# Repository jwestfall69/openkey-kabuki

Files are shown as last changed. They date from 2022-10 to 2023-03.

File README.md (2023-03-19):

# openkey-kabuki
* [Overview](#overview)
* [Project Status](#project-status)
* [Supported Games](#supported-games)
  * [Mitchell](#mitchell)
  * [CPS 1.5 (QSound CPU)](#cps-15-qsound-cpu)
* [Hardware](#hardware)
  * [PCB Manufacturing](#pcb-manufacturing)
  * [BOM](#bom)
  * [Assembly](#assembly)
* [Programming](#programming)
  * [Hardware](#hardware-1)
  * [Software](#software)
* [Installation](#installation)
  * [Mitchell DBS Identify/Removal](#mitchell-dbs-identifyremoval)
  * [CPS 1.5 (QSound CPU) DBS Identify/Removal](#cps-15-qsound-cpu-dbs-identifyremoval)

## Overview
This is an opensource/hardware implementation of an on the fly kabuki CPU key programmer that consists of a PCB that sits between the CPU socket and the kabuki CPU.  The kabuki CPU is found in Mitchell and CPS 1.5 arcade boards and contains keys for decrypting/decoding the program roms.

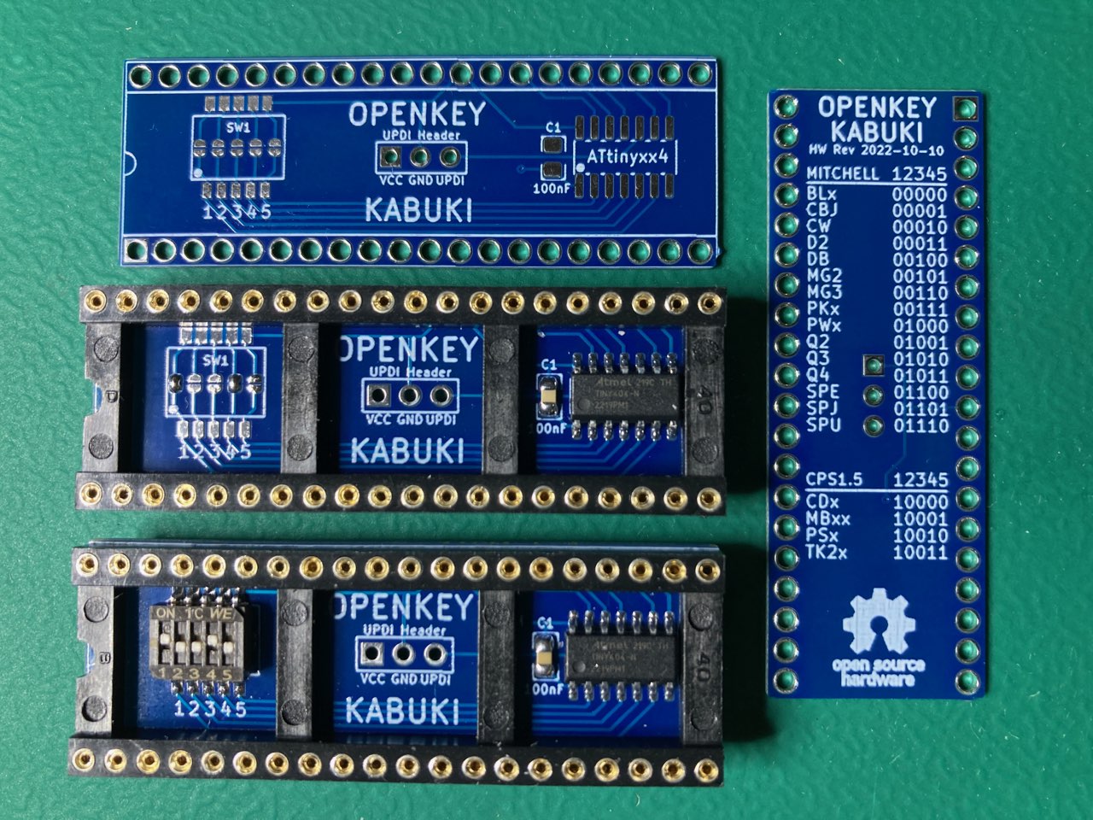
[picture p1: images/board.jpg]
board pics


Installed:<br>
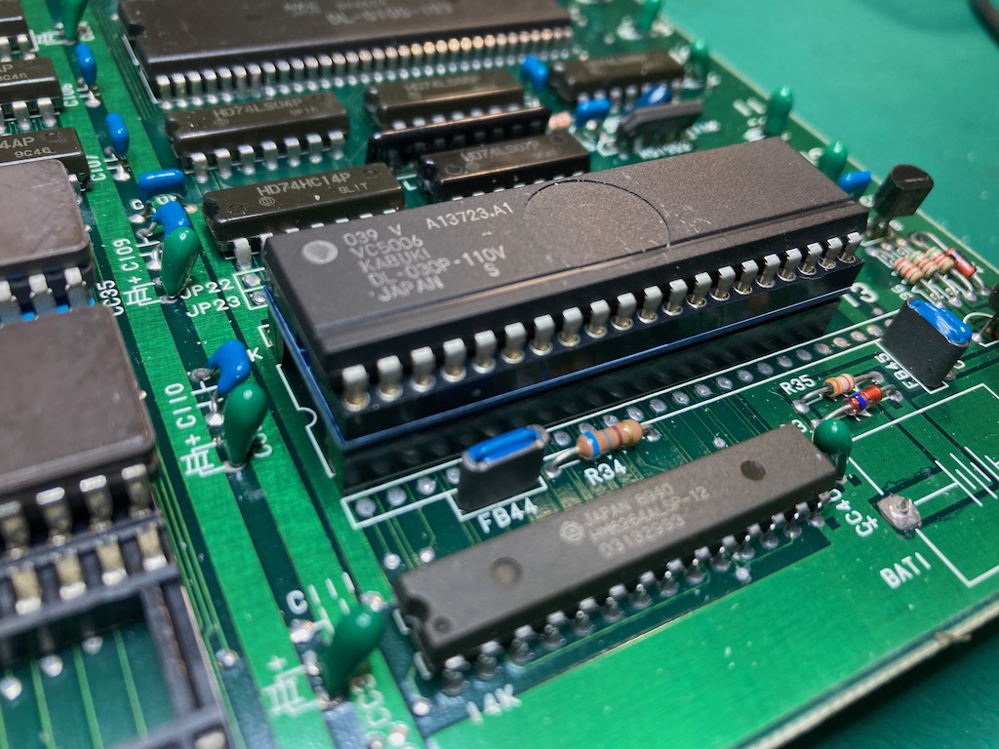
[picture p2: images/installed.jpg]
installed


This project is providing the same functionality as [Undamned's InfiniKey-Kabuki](https://www.arcade-projects.com/threads/infinikey-kabuki.8338/).  The lack of supply is what prompted me to make openkey-kabuki.  If they ever end up coming back in stock please consider purchasing those to support [Undamned](https://www.arcade-projects.com/forums/temple-of-the-undamned.77/)'s work.

Details on *how* to program a kabuki CPU's key data can be found in [Eduardo Cruz](http://arcadehacker.blogspot.com/)'s [write up](http://arcadehacker.blogspot.com/2014/11/capcom-kabuki-cpu-intro.html) and [youtube video](https://www.youtube.com/watch?v=9t-9hQEOjLI).

Details on *what* to program can be found in MAME's decryption code for the [kabuki CPU](https://github.com/mamedev/mame/blob/master/src/mame/capcom/kabuki.cpp#L73).

## Project Status
**PCB:** I would consider the design PCB done at this point.  I'm open to any input on changes/improvements as this is my first PCB design.

**Firmware:** Need to get untested games tested

**Documentation:** Done

## Supported Games
openkey-kabuki supports either having a 5 position switch or using solder jumpers for picking which game key to use.  For the switch, ensure the switches are fully set.  You should hear a click sound as you change the position.

Below is a list of supported games and what switches/jumpers must be used for each.

#### Mitchell
| Switch<br>12345 | Program ROM Labels | MAME Sets | Game Names | Tested / Working |
|---|:---:|---|---|:---:|
| 00000 | BLE<br>BLJ | block<br>blockj | Block Block | YES (conversion)|
| 00001 | CBJ | cbasebal | Capcom Baseball | |
| 00010 | CW | cworld | Capcom World | YES (conversion) |
| 00011 | D2 | dokaben2 | Dokaben 2 | YES (conversion) |
| 00100 | DB | dokaben | Dokaben | YES (conversion) |
| 00101 | MG2 | mgakuen2 | Mahjong Gakuen 2 Gakuen-chou no Fukushuu | YES |
| 00110 | MG3 | marukin | Super Marukin-Ban | YES (conversion) |
| 00111 | PK<br>PKO | pkladiesl<br>pkladies | Poker Ladies | YES (conversion) |
| 01000 | PWE<br>PWJ<br>PWU | pang<br>pompingw<br>bbros | Pang<br>Pomping World<br>Buster Bros | YES |
| 01001 | Q2 | hatena | Adventure Quiz 2 - Hatena? no Daibouken | YES (conversion) |
| 01010 | Q3 | qtono1 | Quiz Tonosama no Yabou | YES |
| 01011 | Q4 | qsangoku | Quiz Sangokushi | YES |
| 01100 | SPE | spang | Super Pang (World) | YES |
| 01101 | SPJ | spangj | Super Pang (Japan) | YES |
| 01110 | SPU | sbbros | Super Buster Bros | YES |
| 01111 | ??? | ??? | Ashita Tenki ni Naare  (place holder) | |

#### CPS 1.5 (QSound CPU)
| Switch<br>12345 | Program ROM Labels | MAME Sets | Game Names | Tested / Working |
|---|:---:|---|---|:---:|
| 10000 | CDE<br>CDJ<br>CDT<br>CDU | dino<br>dinoj<br>dinoa<br>dinou | Cadillacs and Dinosaurs | |
| 10001 | MBE<br>MBJ<br>MBU<br>MBDE<br>MBDJ | slammast<br>mbomberj<br>slammastu<br>mbombrd<br>mbombrdj | Saturday Night Slam Masters<br>Muscle Bomber<br>Muscle Bomber Duo | YES |
| 10010 | PSE<br>PSH<br>PSJ<br>PSE | punisher<br>punisherh<br>punisherj<br>punisheru | Punisher | YES |
| 10011 | TK2A<br>TK2E<br>TK2J<br>TK2U | wofa<br>wof<br>wofj<br>wofu | Warriors of Fate | YES |

**IMPORTANT**: There is a compatibility issue with the older 92636D-3 revision of the D board.  Specifics on this issue can be found [here](https://www.arcade-projects.com/threads/openkey-kabuki-project.23571/post-370690)

When openkey-kabuki is used on a 92636D-3 board revision you will get:

  * "RAM ERROR" screen on Warriors of Fate
  * "1111 EXCEPTION" screen on Slam Masters
  * "NG" screen on Muscle Bomber Duo
  * A black screen on Punisher and C&D

Thus far I've only seen WOF using this older version of the D board.

The compatibility issue was tracked down to a bug in the D9K1 PAL thats on 92636D-3.  The fix is to upgrade that PAL to D9K2, which is found on the newer revision of the D board (92636D-5).

## Hardware
---
#### PCB Manufacturing
You will want to pick **0.8mm PCB thickness** instead of the default of 1.6mm.  A 1.6mm thick PCB will make the legs on openkey-kabuki to be a little to short and cause it to not be fully secure in the CPU socket.

I've been using [jlcpcb](https://jlcpcb.com/) for PCB manufacturing.  The only real downside I've seen with them is they charge a fee (~$17) if you pick a color other then green or black with 0.8mm PCB thickness.  Also watch out, by default they will add an order number to the silk screen unless you tell them not to.

#### BOM
| Description | Part Number | DigiKey | Mouser | Notes |
|---|---|---|---|---|
| 40 Pin Dip Machine Socket | Adam Tech ICM-640-1-GT-HT | [2057-ICM-640-1-GT-HT-ND](https://www.digikey.com/en/products/detail/adam-tech/ICM-640-1-GT-HT/9832971) | | The specific part number isn't required, but it must be a machined 40 pin dip socket with the cross members in the same locations as seen in the picture at the top of this page. This [part](https://www.aliexpress.us/item/2251832711755702.html) from Aliexpress worked for me as well. |
| ATtiny404 20Mhz | ATTINY404-SSN | [ATTINY404-SSN-ND](https://www.digikey.com/en/products/detail/microchip-technology/ATTINY404-SSN/9947546) | [556-ATTINY404-SSNR](https://www.mouser.com/ProductDetail/Microchip-Technology-Atmel/ATTINY404-SSNR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) | Other ATtiny tinyAVR 0/1/2-series models should be viable as well.  The code compiles to just over 1K in size, so any that have 2k or more of flash should work.  Just note I have only tested with 404s |
| 100nf / 0.1uf SMD Ceramic Capacitor 0805 Size | | | | |
| 5 Position Slide Switch | Würth Elektronik 416131160805 | [732-3855-2-ND](https://www.digikey.com/en/products/detail/w%C3%BCrth-elektronik/416131160805/3174531) | [710-416131160805](https://www.mouser.com/ProductDetail/Wurth-Elektronik/416131160805?qs=2kOmHSv6VfT1rqUsojuQog%3D%3D) | **Optional** not needed if using the solder jumpers to pick the game.  This part more then doubles the BOM cost. |

**NOTE**: Additional components maybe needed if you need to revert any previously made desuicide modifications to the arcade PCB.  Check the Installation section at the bottom for details.

#### Assembly
The first thing you should do is a test fit of the socket into the openkey-kabuki PCB.  I came across a couple PCBs in a batch that didn't fit and wasn't until after I had soldered the SMD components that I found this out.

As you can see in the first socket in the picture below the pins start out wide then go skinny.  Normally the wide part is used to keep the socket up off a board, however the openkey-kabuki PCB has extra wide through holes to allow it to sit flush with the plastic part of the socket.  Doing this allows the pins from the socket to be long enough to fit properly into the CPU socket of the arcade board.

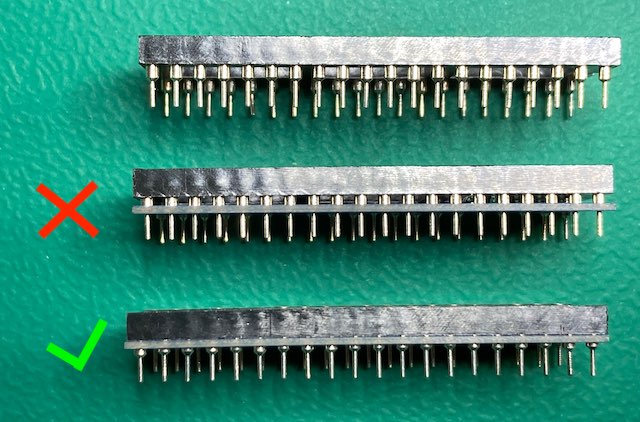
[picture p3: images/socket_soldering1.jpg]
socket soldering1


You should solder the SMD components first.  Take special care to void getting any solder into any of the socket through holes.

  * If you install the dip switch block I would advise testing it
  * If you are using the solder jumpers instead, these can be done now or after everything is fully assembled.

When soldering the socket its best to not use a ton of solder.  The below picture is a board where the socket hasn't been soldered in yet.

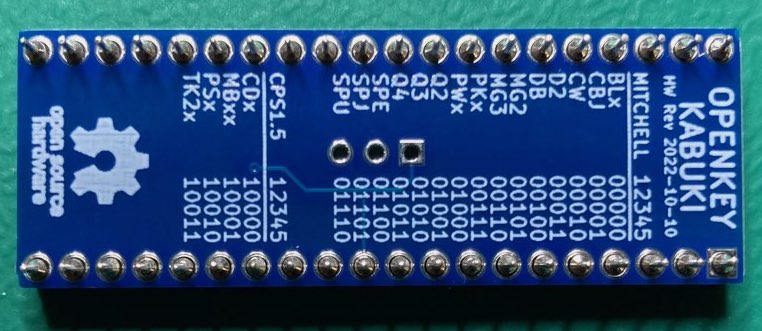
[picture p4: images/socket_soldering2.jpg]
socket soldering2


Note the small gap between the through holes and socket pins.  Solder will naturally want to wick up into that gap.  I generally just use enough solder so that the gap around the socket pin becomes filled.

Once you have completed soldering the socket you should check the skinny part of the pins to verify there aren't any solder blobs on them.  These could cause damage to the CPU socket.

## Programming
#### Hardware
Programming is done with a UPDI programmer.  I've been using this one:

[Serial UPDI Programmer for ATmega 0-Series, or ATtiny 0-Series or 1-Series, or AVR DA or AVR DB](https://www.amazon.com/dp/B09X64YRLD?psc=1&ref=ppx_yo2ov_dt_b_product_details)

Note: This programmer (and likely others) has a switch for 3.3V and 5V.  Set it to 5V.

The openkey-kabuki programming port is setup so you can wedge the pins from the above programmer directly into them to programming.

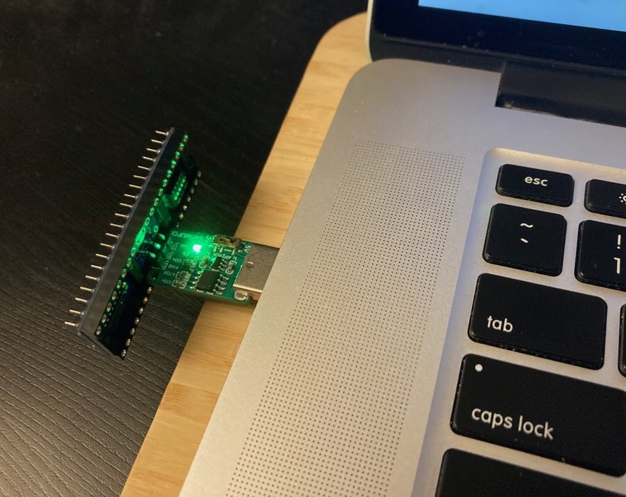
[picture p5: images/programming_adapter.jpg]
programming adapter


Of course be sure you properly orient the board so the labeled pin/holes match up.  vcc to vcc, gnd to gnd, and updi to updi.

#### Software
For software I've been using the [Arduino IDE](https://www.arduino.cc/en/software/OldSoftwareReleases) with [megaTinyCore](https://github.com/SpenceKonde/megaTinyCore), which adds support for tinyAVR 0/1/2-Series MCUs.

**NOTE**: The makers of megaTinyCore currently recommend using Arduino IDE version 1.8.13 for best compatibility.  2.0 definitely does not work!

To install the megaTinyCore you, should just need to add http://drazzy.com/package_drazzy.com_index.json to "Additional Boards Manager URLs" in the settings for the Arduino IDE.

From there you need to configure the board/programming settings.  I've been using these:

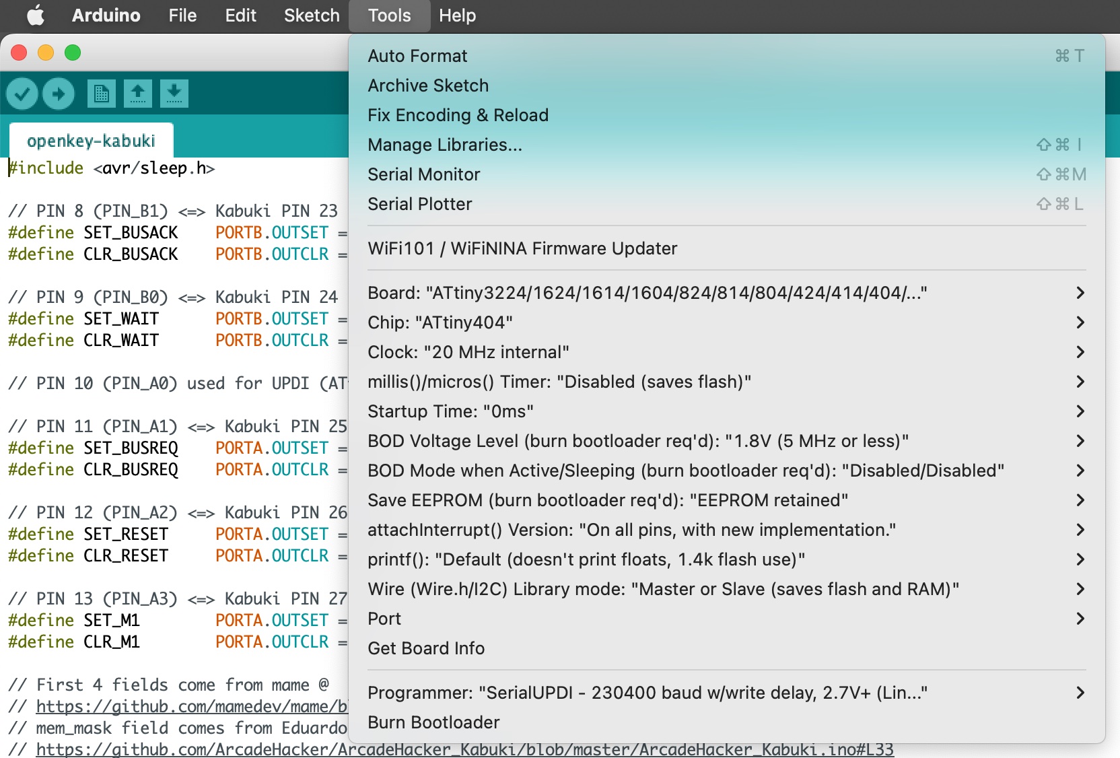
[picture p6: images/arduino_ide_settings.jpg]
arduino ide settings


## Installation
Prior to installing openkey-kabuki you should verify you don't have the [The Dead Battery Society](http://www.arcadecollecting.com/dead/) mod installed on your mitchell or cps 1.5 D board.  Part of the DBS mod is to tie pin 28 of the kabuki CPU to GND.  This pin is normally fed voltage from the battery/vcc to supply the CPU with power for its internal ram holding the key data.  openkey-kabuki will not function unless this is reverted.

Below is how you can identify if the DBS mod is been installed and how to remove it.

#### Mitchell DBS Identify/Removal
This is what a dead battery society mod will look like
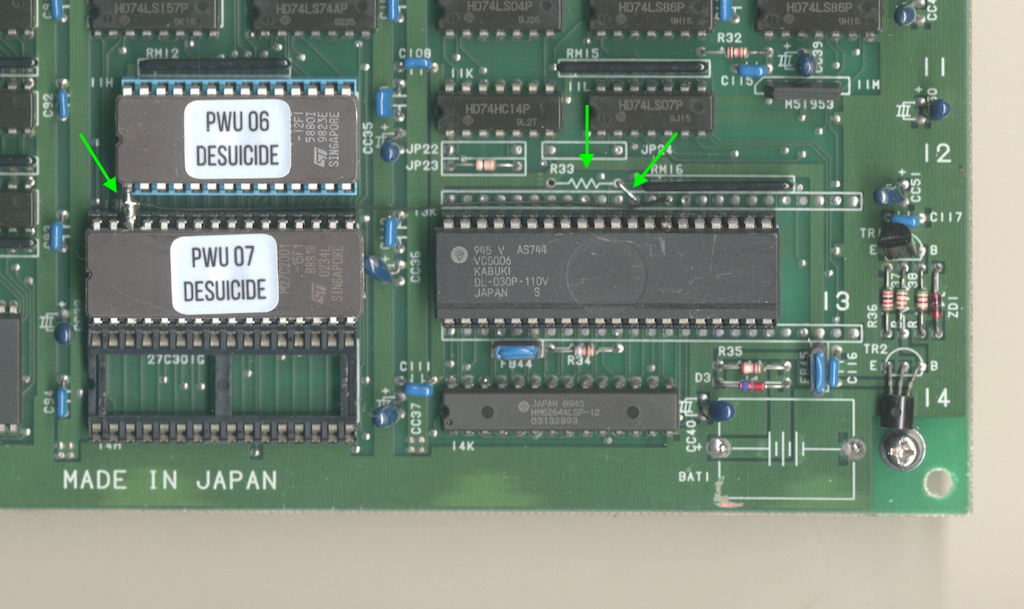
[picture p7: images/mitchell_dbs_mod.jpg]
mitchell dbs

 * R33 (1k ohm resistor) is missing
 * Right through hole of R33 is bridged to the lower right
 * Those pins on the program roms are soldered together and have a wire from them to a pin on the cpu
 * Modified program roms

 All of these things will need to be reverted in order to use openkey-kabuki.  This is what an unmodified board should look like.

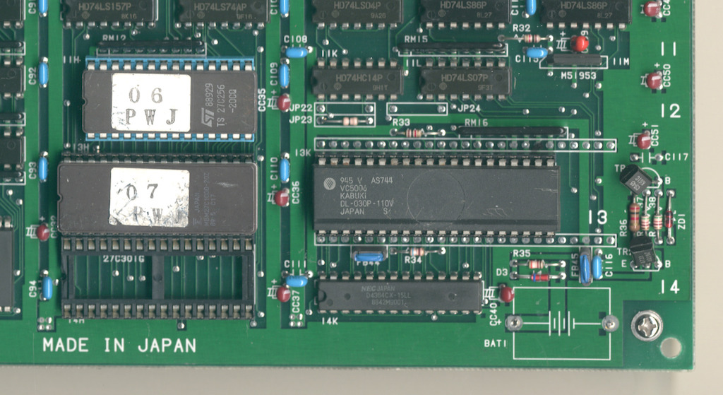
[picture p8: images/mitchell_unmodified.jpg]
mitchell unmodified
 

#### CPS 1.5 (QSound CPU) DBS Identify/Removal

This is what the dead battery society mod will look like on the QSound board of a cps 1.5 game.

Top Side:<br>
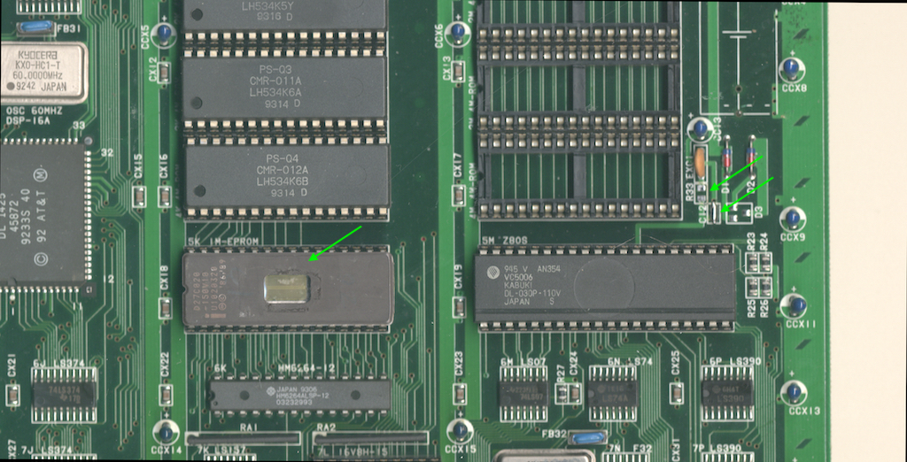
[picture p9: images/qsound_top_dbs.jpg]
qsound top dbs

* R33 (1 ohm resistor 0805 size) is missing
* C12 (100nf capacitor 0805 size) is replaced with a jumper
* Modified QSound program rom

Bottom Side:<br>
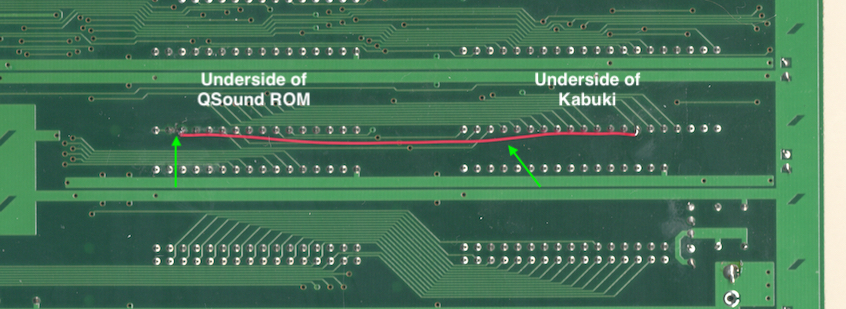
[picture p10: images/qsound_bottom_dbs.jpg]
qsound bottom dbs

* Wire running from QSound program rom pin 30 to Kabuki CPU pin 27
* Cut trace between QSound program rom pins 30 and 31

There will be additional changes specific to slam masters / muscle bomber which are not covered above.

Once reverted it should look like this

Top Side:<br>
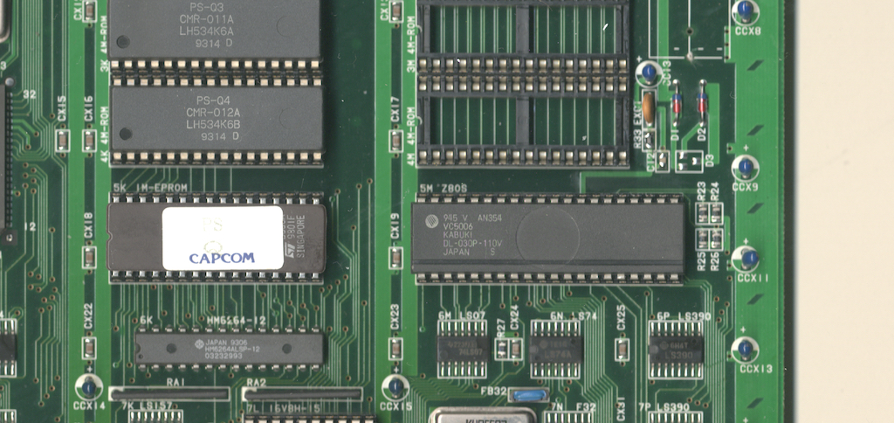
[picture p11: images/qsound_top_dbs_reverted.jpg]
qsound top dbs reverted


Bottom Side:<br>
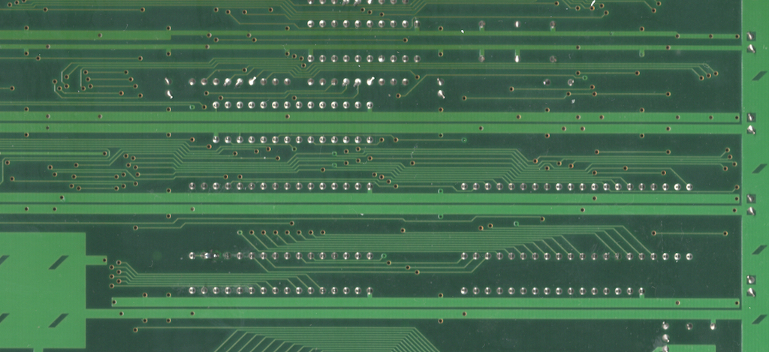
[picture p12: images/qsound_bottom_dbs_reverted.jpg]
qsound bottom dbs reverted


Its hard to tell from the picture, but pins 30 and 31 on the QSound program rom are jumper'd together.

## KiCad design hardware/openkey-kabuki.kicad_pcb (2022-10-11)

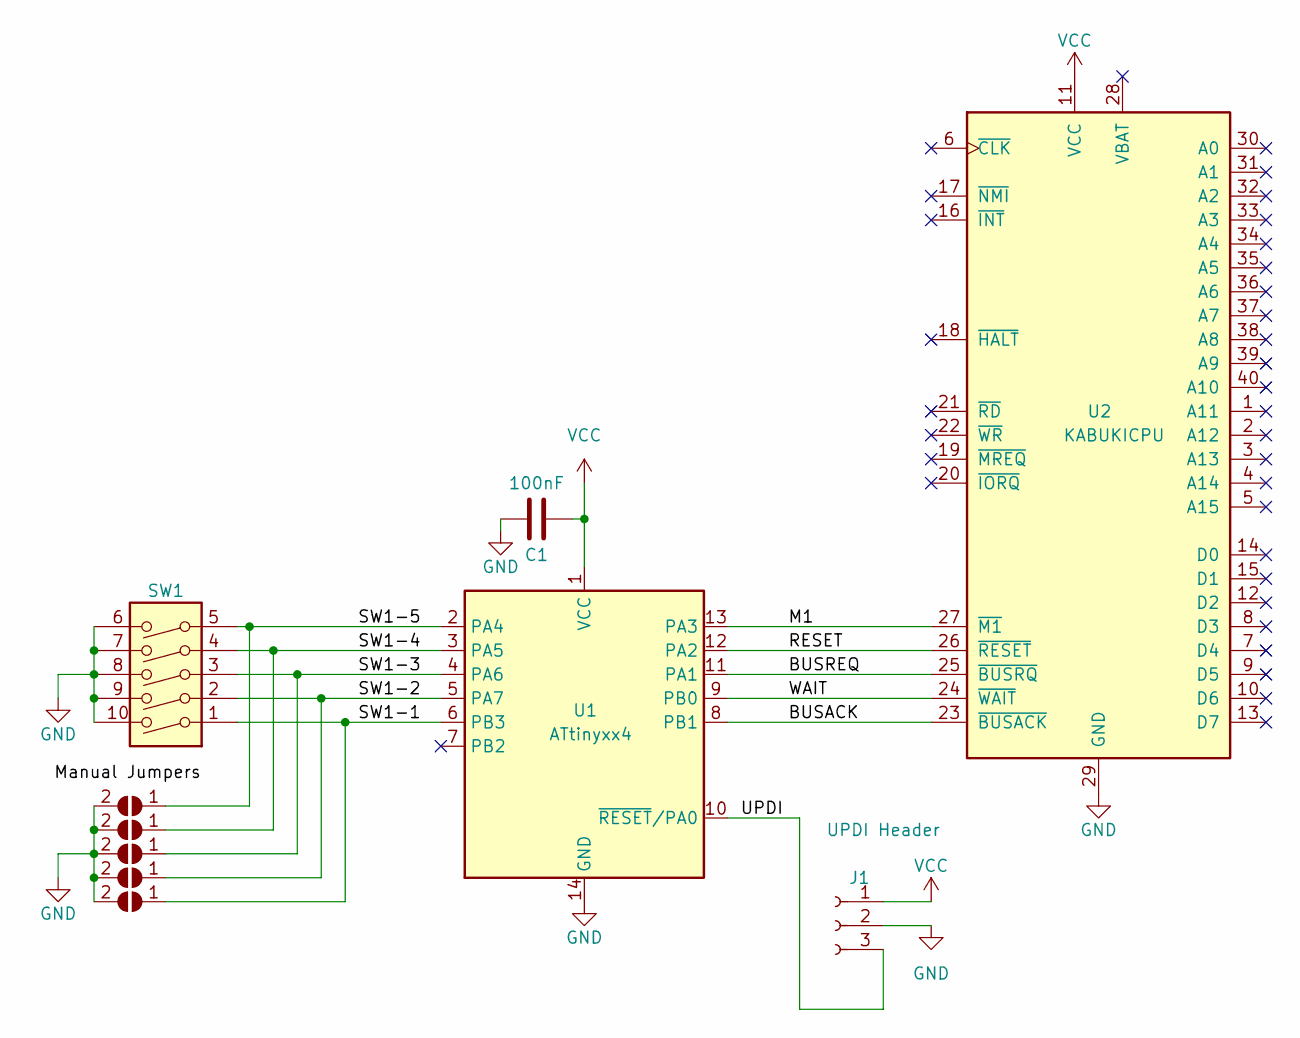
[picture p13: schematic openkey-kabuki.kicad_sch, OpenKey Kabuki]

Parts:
C1: 100nF; C_0805_2012Metric_Pad1.18x1.45mm_HandSolder
J1: UPDI Header; PinHeader_1x03_P2.54mm_Vertical
JP1, JP2, JP3, JP4, JP5: SolderJumper_2_Open; SolderJumper-2_P1.3mm_Open_Pad1.0x0.6mm
SW1: Wurth Elektronik 416131160805; SW_DIP_SPSTx05_Slide_Wurth_416131160805_W7.62mm_P1.27mm
U1: ATtinyxx4; SOIC-14_3.9x8.7mm_P1.27mm
U2: KABUKICPU; DIP-40_W15.24mm_Socket_Wide_Holes

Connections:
/BUSACK: U1.8 (PB1), U2.23 (~BUSACK)
/BUSREQ: U1.11 (PA1), U2.25 (~BUSRQ)
/M1: U1.13 (PA3), U2.27 (~M1)
/RESET: U1.12 (PA2), U2.26 (~RESET)
/SW1-1: JP1.1 (A), SW1.1, U1.6 (PB3)
/SW1-2: JP2.1 (A), SW1.2, U1.5 (PA7)
/SW1-3: JP3.1 (A), SW1.3, U1.4 (PA6)
/SW1-4: JP4.1 (A), SW1.4, U1.3 (PA5)
/SW1-5: JP5.1 (A), SW1.5, U1.2 (PA4)
/UPDI: J1.3, U1.10 (~RESET/PA0)
/WAIT: U1.9 (PB0), U2.24 (~WAIT)
GND: C1.2, J1.2, JP1.2 (B), JP2.2 (B), JP3.2 (B), JP4.2 (B), JP5.2 (B), SW1.6, SW1.7, SW1.8, SW1.9, SW1.10, U1.14 (GND), U2.29 (GND)
VCC: C1.1, J1.1, U1.1 (VCC), U2.11 (VCC)

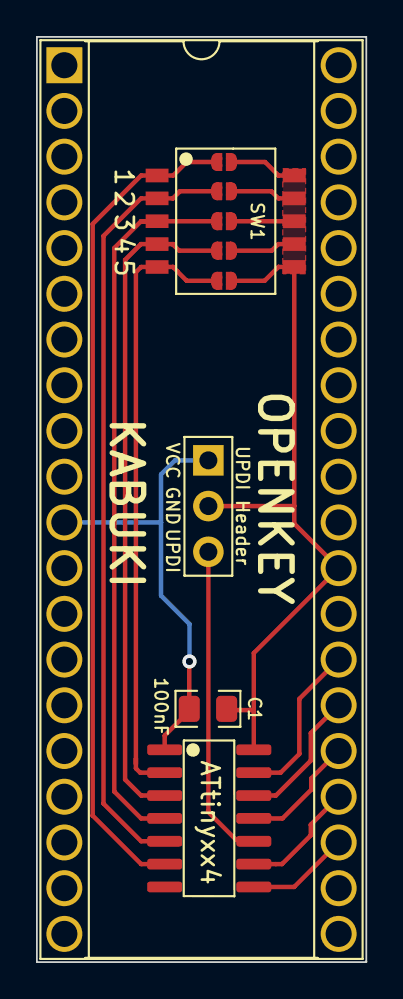
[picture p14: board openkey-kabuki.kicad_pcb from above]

Board: 2 copper layers, 18.3 x 51.4 mm, 10 parts (0 on the bottom side), 13 nets.

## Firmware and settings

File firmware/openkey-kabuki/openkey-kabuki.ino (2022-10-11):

#include <avr/sleep.h>

// PIN 8 (PIN_B1) <=> Kabuki PIN 23 (BUSACK)
#define SET_BUSACK    PORTB.OUTSET = PIN1_bm
#define CLR_BUSACK    PORTB.OUTCLR = PIN1_bm

// PIN 9 (PIN_B0) <=> Kabuki PIN 24 (WAIT)
#define SET_WAIT      PORTB.OUTSET = PIN0_bm
#define CLR_WAIT      PORTB.OUTCLR = PIN0_bm

// PIN 10 (PIN_A0) used for UPDI (ATtiny programming)

// PIN 11 (PIN_A1) <=> Kabuki PIN 25 (BUSREQ)
#define SET_BUSREQ    PORTA.OUTSET = PIN1_bm
#define CLR_BUSREQ    PORTA.OUTCLR = PIN1_bm

// PIN 12 (PIN_A2) <=> Kabuki PIN 26 (RESET)
#define SET_RESET     PORTA.OUTSET = PIN2_bm
#define CLR_RESET     PORTA.OUTCLR = PIN2_bm

// PIN 13 (PIN_A3) <=> Kabuki PIN 27 (M1)
#define SET_M1        PORTA.OUTSET = PIN3_bm
#define CLR_M1        PORTA.OUTCLR = PIN3_bm

// First 4 fields come from mame @
// https://github.com/mamedev/mame/blob/master/src/mame/capcom/kabuki.cpp#L73
// mem_mask field comes from Eduardo Cruz (ArcadeHacker). 
// https://github.com/ArcadeHacker/ArcadeHacker_Kabuki/blob/master/ArcadeHacker_Kabuki.ino#L33
typedef struct game_key_t {
  uint32_t swap_key1;
  uint32_t swap_key2;
  uint16_t address_key;
   uint8_t xor_key;
  uint16_t mem_mask;
} game_key;

#define MAX_GAME_NUM   20
game_key game_keys[MAX_GAME_NUM + 1] = {
  // mitchell games                                      dsw
  //   skey1       skey2     addr    xor   mask         12345
  { 0x02461357, 0x64207531, 0x0002, 0x01, 0x7000 },  // 00000 [BLx] Block Block (BLE, BLJ)
  { 0x01234567, 0x76543210, 0x6548, 0x24, 0x7000 },  // 00001 [CBJ] Capcom Baseball
  { 0x04152637, 0x40516273, 0x5751, 0x43, 0x7000 },  // 00010 [CW]  Capcom World
  { 0x76543210, 0x01234567, 0xaa55, 0xa5, 0x7000 },  // 00011 [D2]  Dokaben 2
  { 0x76543210, 0x01234567, 0xaa55, 0xa5, 0x7000 },  // 00100 [DB]  Dokaben
  { 0x76543210, 0x01234567, 0xaa55, 0xa5, 0x7000 },  // 00101 [MG2] Mahjong Gakuen 2 Gakuen-chou no Fukushuu
  { 0x54321076, 0x54321076, 0x4854, 0x4f, 0x7000 },  // 00110 [MG3] Super Marukin-Ban
  { 0x76543210, 0x01234567, 0xaa55, 0xa5, 0x7000 },  // 00111 [PKx] Poker Ladies (PK, PKO)
  { 0x01234567, 0x76543210, 0x6548, 0x24, 0xf000 },  // 01000 [PWx] Pang / Buster Bros / Pomping World (PWE, PWJ, PWU)
  { 0x45670123, 0x45670123, 0x5751, 0x43, 0x7000 },  // 01001 [Q2]  Adventure Quiz 2 Hatena ? no Dai-Bouken
  { 0x12345670, 0x12345670, 0x1111, 0x11, 0x7000 },  // 01010 [Q3]  Quiz Tonosama no Yabou
  { 0x23456701, 0x23456701, 0x1828, 0x18, 0x7000 },  // 01011 [Q4]  Quiz Sangokushi
  { 0x45670123, 0x45670123, 0x5852, 0x43, 0x7000 },  // 01100 [SPE] Super Pang World
  { 0x45123670, 0x67012345, 0x55aa, 0x5a, 0x7000 },  // 01101 [SPJ] Super Pang Japan
  { 0x45670123, 0x45670123, 0x2130, 0x12, 0x7000 },  // 01110 [SPU] Super Buster Bros
  { 0x00000000, 0x00000000, 0x0000, 0x00, 0x0000 },  // 01111 [???] Ashita Tenki ni Naare (unknown)

  // cps1.5 games                                        dsw
  //   skey1       skey2     addr    xor   mask         12345
  { 0x76543210, 0x24601357, 0x4343, 0x43, 0xff00 },  // 10000 [CDx] Cadillacs and Dinosaurs (CDE, CDJ, CDT, CDU)
  { 0x54321076, 0x65432107, 0x3131, 0x19, 0xff00 },  // 10001 [MBx] Slam Masters (MBDE, MBDJ, MBE, MBJ, MBU)
  { 0x67452103, 0x75316024, 0x2222, 0x22, 0xff00 },  // 10010 [PSx] Punisher (PS, PSE, PSH, PSU)
  { 0x01234567, 0x54163072, 0x5151, 0x51, 0xff00 },  // 10011 [TKx] Warrior of Fate (TK2A, TK2E, TK2J, TK2U)

  // bad dsw value / zero key
  { 0x00000000, 0x00000000, 0x0000, 0x00, 0x0000 }
};

// doing bit shifting takes a variable amount
// of time depending on the how far the shift
// is.  Using the below lookup table to keep
// a consistent clock period when masking a
// bit to send. 
uint32_t masks[32] = {
  0x00000001, 0x00000002, 0x00000004, 0x00000008,
  0x00000010, 0x00000020, 0x00000040, 0x00000080,
  0x00000100, 0x00000200, 0x00000400, 0x00000800,
  0x00001000, 0x00002000, 0x00004000, 0x00008000,
  0x00010000, 0x00020000, 0x00040000, 0x00080000,
  0x00100000, 0x00200000, 0x00400000, 0x00800000,
  0x01000000, 0x02000000, 0x04000000, 0x08000000,
  0x10000000, 0x20000000, 0x40000000, 0x80000000,
};

void setup() {
  
  // wait a bit for other IC's on the board to get
  // in their inital states
  delay(100);

  // wait for the WAIT pin on the kabuki to go high
  // before we do anything
  while(!PORTB.IN & PIN0_bm) { }
  
  // set the pins to kabuki as outputs
  PORTA.DIR = PIN1_bm | PIN2_bm | PIN3_bm;
  PORTB.DIR = PIN0_bm | PIN1_bm;

  // stage #1: set initial output states
  // https://www.youtube.com/watch?v=9t-9hQEOjLI&t=754s
  CLR_RESET;
  CLR_WAIT;
  CLR_BUSREQ;
  SET_M1;
  SET_BUSACK;

  // enable pull-ups on dsw pins
  PORTA.PIN4CTRL |= PORT_PULLUPEN_bm;  // PIN 2 (PIN_PA4) <=> DSW5
  PORTA.PIN5CTRL |= PORT_PULLUPEN_bm;  // PIN 3 (PIN_PA5) <=> DSW4
  PORTA.PIN6CTRL |= PORT_PULLUPEN_bm;  // PIN 4 (PIN_PA6) <=> DSW3
  PORTA.PIN7CTRL |= PORT_PULLUPEN_bm;  // PIN 5 (PIN_PA7) <=> DSW2
  PORTB.PIN3CTRL |= PORT_PULLUPEN_bm;  // PIN 6 (PIN_PB3) <=> DSW1

  // stage #2: door knock #1
  // https://www.youtube.com/watch?v=9t-9hQEOjLI&t=871s
  for(int i = 0;i < 3;i++) {
    SET_BUSREQ;
    CLR_BUSREQ;
  }

  // stage #3: unlock key
  // https://www.youtube.com/watch?v=9t-9hQEOjLI&t=1274s
  send_data(0xb7a45, 20, -1);

  // stage #4: door knock #2
  // https://www.youtube.com/watch?v=9t-9hQEOjLI&t=1433s
  for(int i = 0;i < 10;i++) {
    CLR_M1;
    SET_M1;
  }

  uint8_t game_num = read_dsw();
  if(game_num > MAX_GAME_NUM) {
    game_num = MAX_GAME_NUM;
  }

  // stage #5: 108-bit programming
  // https://www.youtube.com/watch?v=9t-9hQEOjLI&t=1518s
  send_data(0x0, 20, -1);
  send_data(game_keys[game_num].address_key, 16, -1);

  // mame swap keys are 32bit, but the actual swap key is 24bit.
  // the conversion process is to drop the top bit from each nibble.
  // below we are looping over each nibble and only sending the
  // lower 3 bits.
  for(int start_bit = 30; start_bit > 0; start_bit -= 4) {
    send_data(game_keys[game_num].swap_key2, 3, start_bit);
  }

  for(int start_bit = 30; start_bit > 0; start_bit -= 4) {
    send_data(game_keys[game_num].swap_key1, 3, start_bit);
  }

  send_data(game_keys[game_num].xor_key, 8, -1);
  send_data(game_keys[game_num].mem_mask, 16, -1);

  // set all pins to be inputs
  PORTA.DIR = 0;
  PORTB.DIR = 0;

  // power down
  set_sleep_mode(SLEEP_MODE_PWR_DOWN);
  sleep_enable();
  sleep_cpu();
}

void loop() {
  while(1) {}
}

// send bits of data starting at start_bit and going MSB to LSB.
// if start_bit is -1, send the last LSB num_bits bits of the data
void send_data(uint32_t data, int8_t num_bits, int8_t start_bit) {
  num_bits--;

  if(start_bit == -1) {
    start_bit = num_bits;
  }

  while(num_bits >= 0) {
    uint32_t bit = data & masks[start_bit];
    if(bit) {
      SET_M1;
    } else {
      CLR_M1;
    }
    CLR_BUSACK;
    SET_BUSACK;
    num_bits--;
    start_bit--;
  }
}

// DSW1 = PB3 = bit4
// DSW2 = PA7 = bit3
// DSW3 = PA6 = bit2
// DSW4 = PA5 = bit1
// DSW5 = PA4 = bit0
uint8_t read_dsw() {
  uint8_t dsw = 0;

  // negate the bits since we are using
  // pull-ups, "on"s will be low
  uint8_t porta = PORTA.IN ^ 0xff;
  uint8_t portb = PORTB.IN ^ 0xff;

  dsw = porta >> 4;
  dsw = dsw | ((portb & 0b0001000) << 1);
  return dsw;
}

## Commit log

2022-10-11 Add openkey-kicad-library as submodule
2022-10-11 board checkin
    [openkey-kabuki.kicad_pcb, openkey-kabuki.kicad_sch]
2022-10-11 Move hardware bits under hardware dir
    [openkey-kabuki.kicad_pcb, openkey-kabuki.kicad_sch]
2022-10-12 Move firmware to a openkey-kabuki sub dir to keep arduino ide happy
2022-10-12 Add exported gerber directories to .gitignore
2022-10-25 Add cap/resistor physical sizes for cps 1.5 dbs revert
2022-10-30 Docs: Suggest doing a test fit of socket before any soldering
2022-11-17 Docs: programmer voltage switch
2022-12-17 Quiz Sangokushi and Quiz Tonosama no Yabou are tested
    Got my hands on these boards and both tested good
2022-12-20 Capcom World and Adventure Quiz 2 tested
    I was able to make conversions of the games to test using my Quiz
    Sangokushi board.
2022-12-20 Poker Ladies and Super Marukin-Ban tested
    I was able to make conversions of the games to test using my Mahjong
    Gakuen 2 board.
2023-01-02 Tweak last doc update
    Forgot in a previous hw rev I removed using pin 28 on the kabuki, so
    the short to ground wont happen if dbs mod is installed.
2023-03-19 Note about compatibility issue and fix with 92636D-3 D boards
    Couple spelling fixes too
